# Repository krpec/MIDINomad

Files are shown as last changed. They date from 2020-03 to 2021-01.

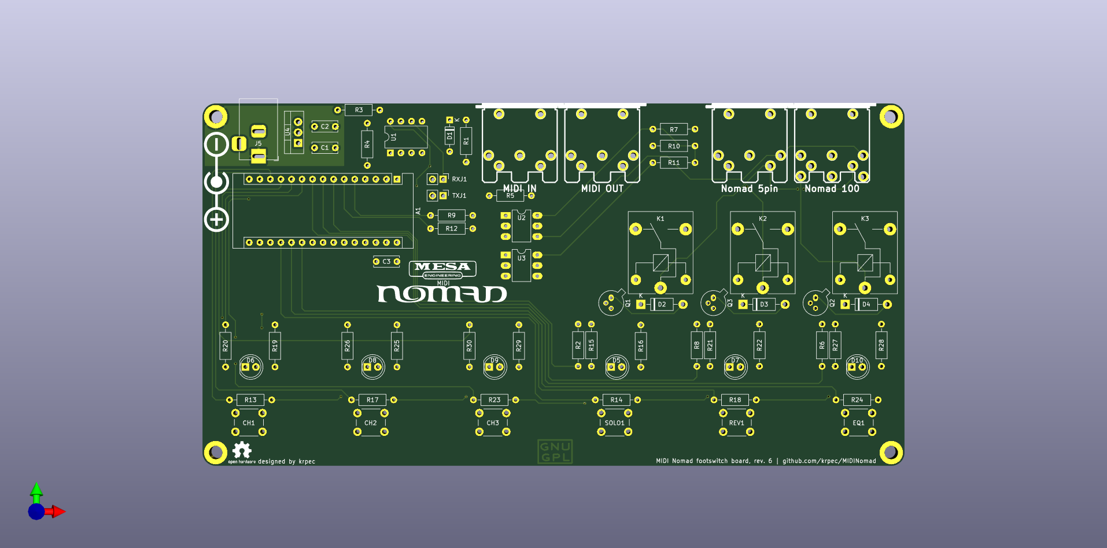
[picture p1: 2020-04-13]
midinomad-pcb-render-rev6.png

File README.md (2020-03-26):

# MIDI Nomad

Arduino-based MIDI capable footswitch replacement for Mesa/Boogie Nomad 100 head.

Inspired by [happyswitch](https://happyswitch.it), [happyswitch github repo](https://github.com/siddolo/happyswitch)

Hackaday.io project can be found here: [MIDI Nomad](https://hackaday.io/project/170576-midi-nomad)

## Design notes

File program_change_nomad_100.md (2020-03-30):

MIDI Program number list, Mesa Nomad 100, Arduino based controller

The program number is a result of a simple formula:
`Pn = channel_value [+ eq] [+ rev] [+ solo]`

CH1 = 0
CH2 = 10
CH3 = 20
EQ = 1
REV = 2
SOLO = 4

With the formula applied, this is the list of all possible programs for Nomad 100:

0.  CH1
1.  CH1 EQ
2.  CH1    REV
3.  CH1 EQ REV
4.  CH1        SOLO
5.  CH1 EQ     SOLO
6.  CH1    REV SOLO
7.  CH1 EQ REV SOLO

---

10. CH2
11. CH2 EQ
12. CH2    REV
13. CH2 EQ REV
14. CH2        SOLO
15. CH2 EQ     SOLO
16. CH2    REV SOLO
17. CH2 EQ REV SOLO

---

20. CH3
21. CH3 EQ
22. CH3    REV
23. CH3 EQ REV
24. CH3        SOLO
25. CH3 EQ     SOLO
26. CH3    REV SOLO
27. CH3 EQ REV SOLO

Arduino will do the mapping of the MIDI program change messages to the proprietary Mesa DIN footswitch connector.

For the FXL8 Pro, the value has to be incremented by one as it does 1-128 range, instead of 0-127.

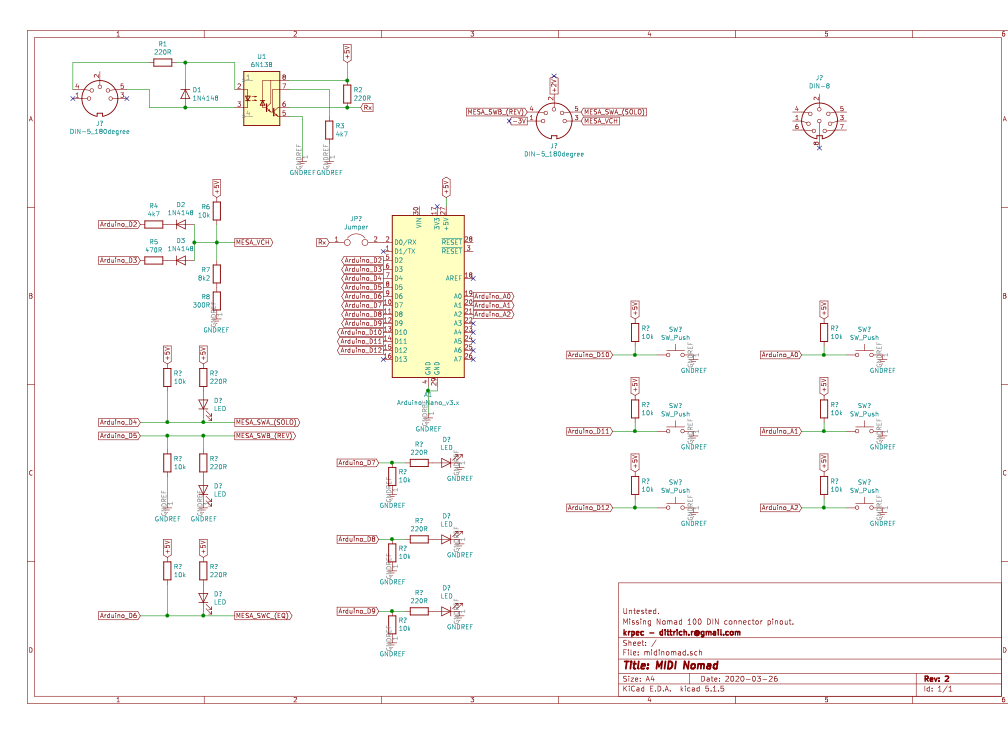
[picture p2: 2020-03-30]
midinomad-schematics.png

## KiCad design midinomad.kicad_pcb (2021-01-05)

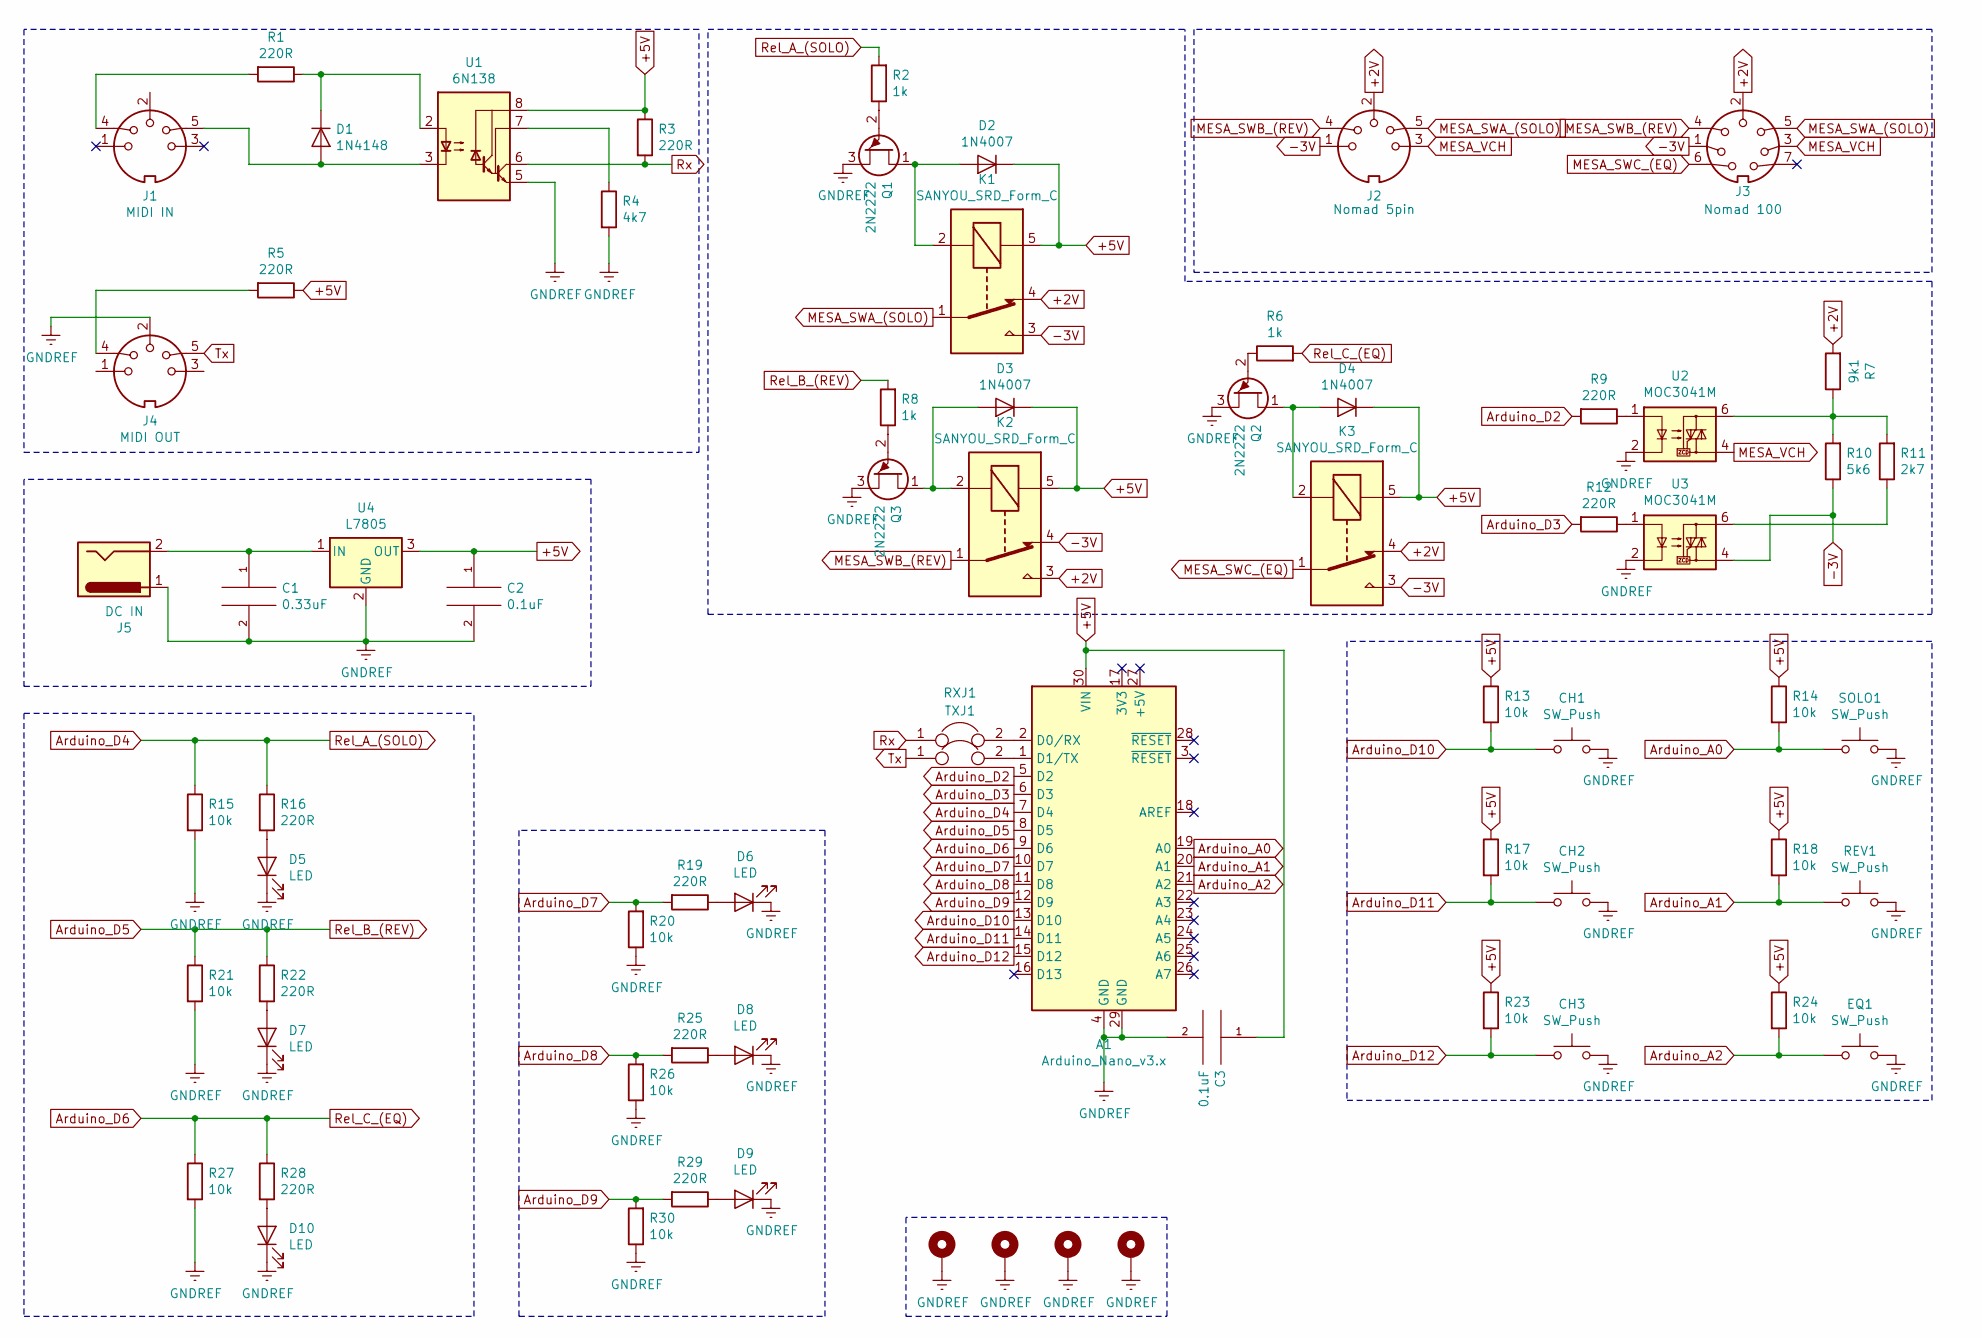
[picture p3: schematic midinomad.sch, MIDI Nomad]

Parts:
A1: Arduino_Nano_v3.x; Arduino_Nano
C1: 0.33uF; C_Disc_D6.0mm_W2.5mm_P5.00mm
C2, C3: 0.1uF; C_Disc_D6.0mm_W2.5mm_P5.00mm
CH1, CH2, CH3: SW_Push; SW_PUSH_6mm
D1: 1N4148; D_DO-35_SOD27_P7.62mm_Horizontal
D2, D3, D4: 1N4007; D_DO-41_SOD81_P10.16mm_Horizontal
D5, D6, D7, D8, D9, D10: LED; LED_D5.0mm
EQ1: SW_Push; SW_PUSH_6mm
H1, H2, H3, H4: MountingHole_Pad; MountingHole_3.2mm_M3_DIN965_Pad
J1: MIDI IN; din-5
J2: Nomad 5pin; din-5
J3: Nomad 100; din-8
J4: MIDI OUT; din-5
J5: DC IN; BarrelJack_Horizontal
K1, K2, K3: SANYOU_SRD_Form_C; Relay_SPDT_SANYOU_SRD_Series_Form_C
Q1, Q2, Q3: 2N2222; TO-92
R1, R3, R5, R9, R12, R16, R19, R22, R25, R28, R29: 220R; R_Axial_DIN0207_L6.3mm_D2.5mm_P10.16mm_Horizontal
R2, R6, R8: 1k; R_Axial_DIN0207_L6.3mm_D2.5mm_P10.16mm_Horizontal
R4: 4k7; R_Axial_DIN0207_L6.3mm_D2.5mm_P10.16mm_Horizontal
R7: 9k1; R_Axial_DIN0207_L6.3mm_D2.5mm_P10.16mm_Horizontal
R10: 5k6; R_Axial_DIN0207_L6.3mm_D2.5mm_P10.16mm_Horizontal
R11: 2k7; R_Axial_DIN0207_L6.3mm_D2.5mm_P10.16mm_Horizontal
R13, R14, R15, R17, R18, R20, R21, R23, R24, R26, R27, R30: 10k; R_Axial_DIN0207_L6.3mm_D2.5mm_P10.16mm_Horizontal
REV1: SW_Push; SW_PUSH_6mm
RXJ1: Jumper; PinHeader_1x02_P2.54mm_Vertical
SOLO1: SW_Push; SW_PUSH_6mm
TXJ1: Jumper; PinHeader_1x02_P2.54mm_Vertical
U1: 6N138; DIP-8_W7.62mm
U2, U3: MOC3041M; DIP-6_W7.62mm_LongPads
U4: L7805; TO-220-3_Vertical

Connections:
+2V: J2.2, J3.2, K1.4, K2.3, K3.4, R7.2
+5V: A1.30 (VIN), C2.1, C3.1, D2.1 (K), D3.1 (K), D4.1 (K), K1.5, K2.5, K3.5, R3.1, R5.1, R13.1, R14.1, R17.1, R18.1, R23.1, R24.1, U1.8 (VCC), U4.3 (OUT)
-3V: J2.1, J3.1, K1.3, K2.4, K3.3, R10.1, U3.4
Arduino_A0: A1.19 (A0), R14.2, SOLO1.1
Arduino_A1: A1.20 (A1), R18.2, REV1.1
Arduino_A2: A1.21 (A2), EQ1.1, R24.2
Arduino_D2: A1.5 (D2), R9.2
Arduino_D3: A1.6 (D3), R12.2
Arduino_D4: A1.7 (D4), R2.2, R15.1, R16.1
Arduino_D5: A1.8 (D5), R8.2, R21.1, R22.1
Arduino_D6: A1.9 (D6), R6.2, R27.1, R28.1
Arduino_D7: A1.10 (D7), R19.2, R20.2
Arduino_D8: A1.11 (D8), R25.2, R26.2
Arduino_D9: A1.12 (D9), R29.2, R30.2
Arduino_D10: A1.13 (D10), CH1.1, R13.2
Arduino_D11: A1.14 (D11), CH2.1, R17.2
Arduino_D12: A1.15 (D12), CH3.1, R23.2
GNDREF: A1.4 (GND), A1.29 (GND), C1.2, C2.2, C3.2, CH1.2, CH2.2, CH3.2, D5.1 (K), D6.1 (K), D7.1 (K), D8.1 (K), D9.1 (K), D10.1 (K), EQ1.2, H1.1, H2.1, H3.1, H4.1, J4.2, J5.1, Q1.3 (B1), Q2.3 (B1), Q3.3 (B1), R4.2, R15.2, R20.1, R21.2, R26.1, R27.2, R30.1, REV1.2, SOLO1.2, U1.5 (GND), U2.2, U3.2, U4.2 (GND)
MESA_SWA_(SOLO): J2.5, J3.5, K1.1
MESA_SWB_(REV): J2.4, J3.4, K2.1
MESA_SWC_(EQ): J3.6, K3.1
MESA_VCH: J2.3, J3.3, U2.4
unnamed: A1.1 (D1/TX), TXJ1.2
unnamed: A1.2 (D0/RX), RXJ1.2
unnamed: C1.1, J5.2, U4.1 (IN)
unnamed: D1.1 (K), R1.1, U1.2 (C1)
unnamed: D1.2 (A), J1.5, U1.3 (C2)
unnamed: D2.2 (A), K1.2, Q1.1 (B2)
unnamed: D3.2 (A), K2.2, Q3.1 (B2)
unnamed: D4.2 (A), K3.2, Q2.1 (B2)
unnamed: D5.2 (A), R16.2
unnamed: D6.2 (A), R19.1
unnamed: D7.2 (A), R22.2
unnamed: D8.2 (A), R25.1
unnamed: D9.2 (A), R29.1
unnamed: D10.2 (A), R28.2
unnamed: J1.4, R1.2
unnamed: J4.4, R5.2
unnamed: Q1.2 (E), R2.1
unnamed: Q2.2 (E), R6.1
unnamed: Q3.2 (E), R8.1
unnamed: R4.1, U1.7 (VO1)
unnamed: R9.1, U2.1
unnamed: R7.1, R10.2, R11.2, U2.6
unnamed: R11.1, U3.6
unnamed: R12.1, U3.1
Rx: R3.2, RXJ1.1, U1.6 (VO2)
Tx: J4.5, TXJ1.1

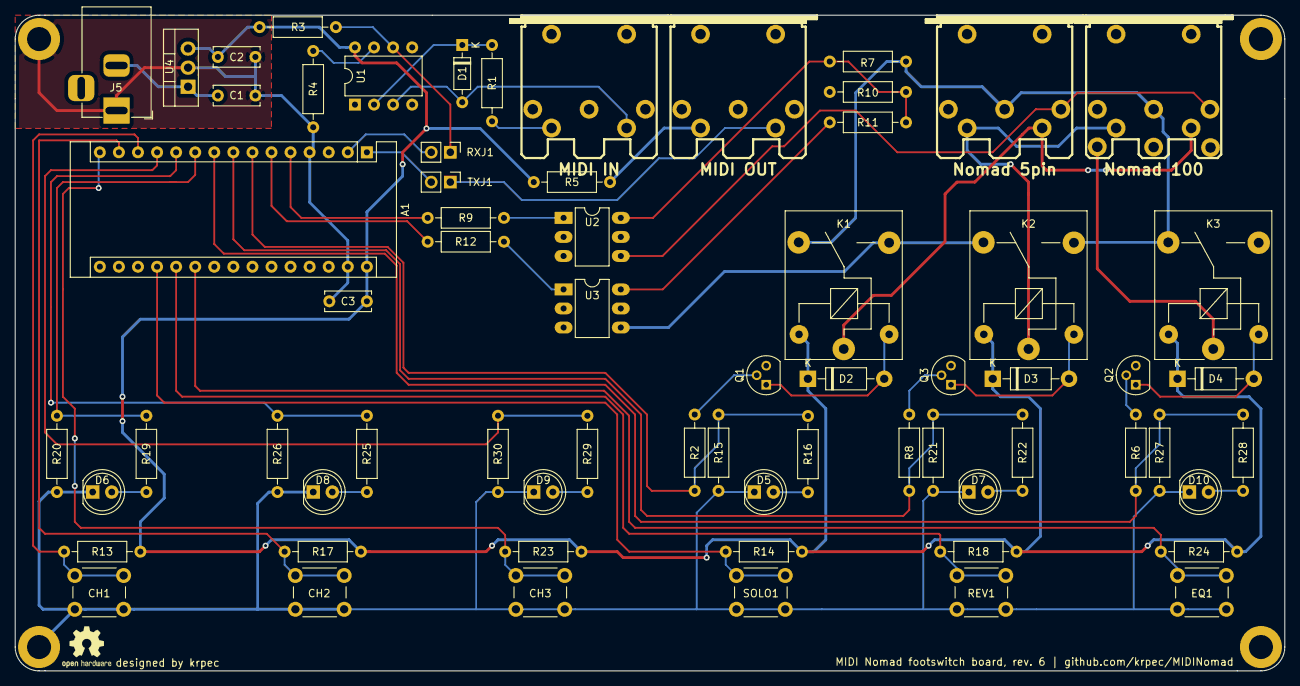
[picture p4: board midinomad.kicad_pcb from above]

Board: 2 copper layers, 169.1 x 87.3 mm, 71 parts (0 on the bottom side), 48 nets.

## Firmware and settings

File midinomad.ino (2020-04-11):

/*
 * MIDINomad Rev.5
 * GNU GPL v3
 * 
 * Code by krpec - dittrich.r@gmail.com
 * Inspired by HappySwitch v2, created by Pasquale 'sid' Fiorillo
 * April 2020
 */

#include <MIDI.h>

#define MIDI_CHANNEL 1

#define REL1 2
#define REL2 3
#define MESA_SWA 4
#define MESA_SWB 5
#define MESA_SWC 6

#define LED_CH1 7
#define LED_CH2 8
#define LED_CH3 9

#define SW_CH1  10
#define SW_CH2  11
#define SW_CH3  12
#define SW_SOLO 14
#define SW_REV  15
#define SW_EQ   16

#define MIDI_VAL_CH1  0
#define MIDI_VAL_CH2  10
#define MIDI_VAL_CH3  20
#define VAL_CH1  16
#define VAL_CH2  32
#define VAL_CH3  64
#define VAL_EQ   1
#define VAL_REV  2
#define VAL_SOLO 4

#define MASK_PRESERVE_CHANNELS 0B01110000
#define MASK_OMMIT_CHANNELS    0B00000111
#define MASK_EQ_OFF            0B01110110
#define MASK_REV_OFF           0B01110101
#define MASK_SOLO_OFF          0B01110011

MIDI_CREATE_DEFAULT_INSTANCE();

byte currentProgram =  VAL_CH2;
byte lock; 

void setChannel(int channel = VAL_CH2) {
  currentProgram &= MASK_OMMIT_CHANNELS;
  currentProgram |= channel;
  
  //handle output change to set correct channel & change the LEDs
  switch (channel) {
    case VAL_CH1:
			//digitalWrite(REL1, HIGH);
			//digitalWrite(REL2, HIGH);
			
      digitalWrite(LED_CH1, HIGH);
      digitalWrite(LED_CH2, LOW);
      digitalWrite(LED_CH3, LOW);
      break;
    case VAL_CH2:
			//digitalWrite(REL1, LOW);
			//digitalWrite(REL2, LOW);
			
      digitalWrite(LED_CH1, LOW);
      digitalWrite(LED_CH2, HIGH);
      digitalWrite(LED_CH3, LOW);
      break;
    case VAL_CH3:
			//digitalWrite(REL1, HIGH);
			//digitalWrite(REL2, LOW);
			
      digitalWrite(LED_CH1, LOW);
      digitalWrite(LED_CH2, LOW);
      digitalWrite(LED_CH3, HIGH);
      break;
  }
}

void functionOn(int f) {
  currentProgram |= f;
  //handle output change to turn the SOLO/REV/EQ on
	switch (f) {
	  case VAL_EQ:
			digitalWrite(MESA_SWC, HIGH);
			break;
		case VAL_REV:
			digitalWrite(MESA_SWB, HIGH);
			break;
		case VAL_SOLO:
			digitalWrite(MESA_SWA, HIGH);
			break;
	}
}

void functionOff(int f) {
  //handle output change to turn the SOLO/REV/EQ off
	switch (f) {
  	case VAL_EQ:
      currentProgram &= MASK_EQ_OFF;
			digitalWrite(MESA_SWC, LOW);
			break;
	  case VAL_REV:
      currentProgram &= MASK_REV_OFF;
			digitalWrite(MESA_SWB, LOW);
			break;
	  case VAL_SOLO:
      currentProgram &= MASK_SOLO_OFF;
			digitalWrite(MESA_SWA, LOW);
			break;
	}
}

void changeProgram(byte num) {
    if (num < VAL_CH2) {
      //change channel to CH1  
      setChannel(VAL_CH1);
    }
    else if (num >= VAL_CH2 && num < VAL_CH3)
    {
      //change channel to ch2  
      setChannel(VAL_CH2);
    }
    else {
      //change channel to ch3
      setChannel(VAL_CH3);
    }

    if ((num & VAL_EQ) == VAL_EQ) {
      functionOn(VAL_EQ);
    }
    else {
      functionOff(VAL_EQ);
    }

    if ((num & VAL_REV) == VAL_REV) {
      functionOn(VAL_REV);
    }
    else {
      functionOff(VAL_REV);
    }

    if ((num & VAL_SOLO) == VAL_SOLO) {
      functionOn(VAL_SOLO);
    }
    else {
      functionOff(VAL_SOLO);
    }
}

void waitUntilButtonReleased() {
  while (lock && !digitalRead(lock)) {
    delay(1);
  }
}

void handleProgramChange(byte channel, byte midiNumber) {
  int number = VAL_CH2;
  
  if (channel == MIDI_CHANNEL) {
    if (midiNumber < MIDI_VAL_CH2) {
      number = midiNumber + VAL_CH1;  
    }
    else if (midiNumber >= MIDI_VAL_CH2 && midiNumber < MIDI_VAL_CH3) {
      number = midiNumber - MIDI_VAL_CH2 + VAL_CH2;
    }
    else {
      number = midiNumber - MIDI_VAL_CH3 + VAL_CH3;
    }
    
    changeProgram(number);
  }
}

void setup() {
  pinMode(REL1, OUTPUT);
  pinMode(REL2, OUTPUT);
  pinMode(MESA_SWA, OUTPUT);
  pinMode(MESA_SWB, OUTPUT);
  pinMode(MESA_SWC, OUTPUT);
  
  pinMode(LED_CH1, OUTPUT);
  pinMode(LED_CH2, OUTPUT);
  pinMode(LED_CH3, OUTPUT);

  pinMode(SW_CH1, INPUT);
  pinMode(SW_CH2, INPUT);
  pinMode(SW_CH3, INPUT);
  pinMode(SW_EQ, INPUT);
  pinMode(SW_REV, INPUT);
  pinMode(SW_SOLO, INPUT);
  
  byte led;
  for (led = LED_CH1; led <= LED_CH3; led++) {
    digitalWrite(led, HIGH);
    delay(300);
    digitalWrite(led, LOW);
  }
  
  //defaults: CH1, SOLO & EQ & REV off
  setChannel(VAL_CH2);
  functionOff(VAL_EQ);
  functionOff(VAL_REV);
  functionOff(VAL_SOLO);

  MIDI.begin(MIDI_CHANNEL_OMNI);
  MIDI.setInputChannel(MIDI_CHANNEL);
  MIDI.turnThruOn(midi::Thru::DifferentChannel);
  MIDI.setHandleProgramChange(handleProgramChange);
}

void loop() {
  //handle the buttons
  lock = 0;
  byte btnConfig = currentProgram;
	byte currentChannel = btnConfig & MASK_PRESERVE_CHANNELS;
	
  if (!digitalRead(SW_CH1)) {
    if (currentChannel != VAL_CH1) {
      btnConfig &= MASK_OMMIT_CHANNELS;
      btnConfig |= VAL_CH1;
      lock = SW_CH1;
    }
  }
  else if (!digitalRead(SW_CH2)) {
    if (currentChannel != VAL_CH2) {
      btnConfig &= MASK_OMMIT_CHANNELS;
      btnConfig |= VAL_CH2;
      lock = SW_CH2;
    }
  }
  else if (!digitalRead(SW_CH3)) {
    if (currentChannel != VAL_CH3) {
      btnConfig &= MASK_OMMIT_CHANNELS;
      btnConfig |= VAL_CH3;
      lock = SW_CH3;
    }
  }
  else if (!digitalRead(SW_EQ)) {
    if ((btnConfig & VAL_EQ) == VAL_EQ) {
      btnConfig &= MASK_EQ_OFF;
    }
    else {
      btnConfig |= VAL_EQ;
    }

    lock = SW_EQ;
  }
  else if (!digitalRead(SW_REV)) {
    if ((btnConfig & VAL_REV) == VAL_REV) {
      btnConfig &= MASK_REV_OFF;
    }
    else {
      btnConfig |= VAL_REV;
    }

    lock = SW_REV;
  }
  else if (!digitalRead(SW_SOLO)) {
    if ((btnConfig & VAL_SOLO) == VAL_SOLO) {
      btnConfig &= MASK_SOLO_OFF;
    }
    else {
      btnConfig |= VAL_SOLO;
    }

    lock = SW_SOLO;
  }

  waitUntilButtonReleased();
  
  if (btnConfig != currentProgram) {
    changeProgram(btnConfig);
  }
  
  //MIDI read here..
  MIDI.read();
}

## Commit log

2020-03-27 Initial schematics, no PCB yet.
    [midinomad.kicad_pcb, midinomad.sch]
2020-03-30 Updated schematics. Still work in progress.
    [midinomad.kicad_pcb, midinomad.sch]
2020-03-31 Schematics update, arduino code finished.
    [midinomad.sch]
2020-04-01 schematics related changes
    [midinomad.sch]
2020-04-04 schematics updated, using analog mux for vch switching, PCB nearly done
    [midinomad.kicad_pcb, midinomad.sch]
2020-04-05 Rev 4 schematics, rev 3 pcb
    [midinomad.kicad_pcb]
2020-04-05 forgot to f*$%ing save the changes..
    [midinomad.kicad_pcb]
2020-04-05 PCB rev. 4
    [midinomad.kicad_pcb]
2020-04-07 Updated both schematics & PCB, added second 74hc4053.
    [midinomad.kicad_pcb, midinomad.sch]
2020-04-11 schematics changes
    [midinomad.kicad_pcb]
2020-04-13 Rev. 6 PCB & schematics
    [midinomad.kicad_pcb, midinomad.sch]
2021-01-05 before adding the rest of relays
    [midinomad.kicad_pcb, midinomad.sch]
